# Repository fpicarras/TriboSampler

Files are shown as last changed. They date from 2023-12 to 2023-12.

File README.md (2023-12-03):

# Portable Sampler for Textile Triboelectric Nano-Generators (TENGs) Wearable Sensor System

## Overview

Textile triboelectric nano-generators (TENGs) have emerged as a promising solution for wearable self-powered sensing technology. These flexible TENGs exhibit stable output performance under strong deformation and can be utilized as wearable sensors to monitor biomechanical movements. In this internship project, we focused on the conceptualization of a small, portable electronic device capable of harnessing signals produced by TENGs as sensors and processing the acquired data.

## Objectives

The primary goal of this internship was to explore the potential of TENGs as wearable sensors and to design a system that efficiently captures and transmits the biomechanical movement data.

## Challenges and Solutions

Despite the initial aim of achieving self-sustainability for the electronic device using TENGs, practical limitations were encountered. As a result, we decided to design a low-power and low-profile system powered by two single coin batteries. This system is capable of sampling the sensor data and transmitting it to another device with higher processing capabilities, allowing for more efficient real-time data management.

## System Design

The designed system consists of:
- **Textile Triboelectric Nano-Generators (TENGs):** Serving as wearable sensors to capture biomechanical movement data.
- **Low-Power Circuit:** Powered by two single coin batteries, capable of efficiently sampling the sensor data.
- **Data Transmission:** The system transmits captured data to another device with higher processing capabilities for real-time management.

## Future Considerations

Although the current implementation relies on coin batteries for power, future iterations may explore alternative power sources or energy-efficient improvements to enhance device sustainability.

## Usage

To utilize the system:
1. **Wear the TENGs:** Attach the TENGs to the desired wearable locations.
2. **Power On:** Ensure the low-power circuit is powered by two single coin batteries.
3. **Data Transmission:** The system will transmit the captured data to another device for real-time monitoring.

## Conclusion

This internship project lays the foundation for the development of a wearable sensor system utilizing TENGs for biomechanical movement monitoring. While the goal of achieving complete self-sustainability remains a future consideration, the current design provides a practical and efficient solution for real-time data management in everyday and medical environments.

**Note:** This README serves as a high-level overview. Refer to the project documentation for detailed technical information and instructions.

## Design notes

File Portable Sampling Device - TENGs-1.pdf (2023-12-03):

# Portable Sampling Device for textile-embedded Triboelectric Nanogenerators Sensors

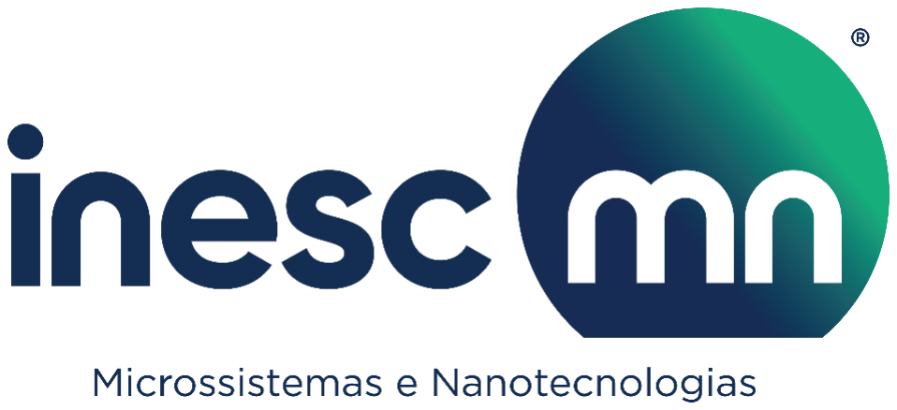
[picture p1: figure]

## Filipe Piçarra

### Ismael Domingos

### Summer Internship at INESC-MN

### Triboelectric Nanogenerators for self-sustainable Wearable Electronics

### August 2023

# Index

## Introduction

Textile triboelectric nano-generators (TENGs) are emerging as a promising solution for wearable self-powered sensing technology. The flexible TENG presents a stable output performance under strong deformation and its sensitivity to movement can be explored as wearable sensor to monitor biomechanical movements. In this Internship, we engaged in the conceptualization of small portable electronic device that could harness the signals produced by the TENGs acting as sensors to further process the data.

While the self-sustainability of the circuit proved unfruitful to power said device, for now, we opted in designing a low-power and low-profile system powered by two single coin batteries who could be able to sample the sensors data and transmit it to another device with higher processing capabilities to more efficiently manage said data in real-time, allowing the users to better track biomechanical movements in a every-day or medical environment.

## Methodology

Throughout the conceptualization and testing of the devices, the following instruments were used:

- Tektronix TBS 1000C Series Digital Oscilloscope
- Agilent 33210A Function Generator
- TriboTester – Perpendicular Oscillatory Movement Stimulator
- Arduino Uno – ADC used to sample the output signal. 10-bit 0 to 5 V ADC with an input impedance of 10 MΩ.

The circuits were tested in TENGs with single electrode configuration, where the sensors were labelled has the positive electrode and another textile surface as it’s negative/reference counterpart.

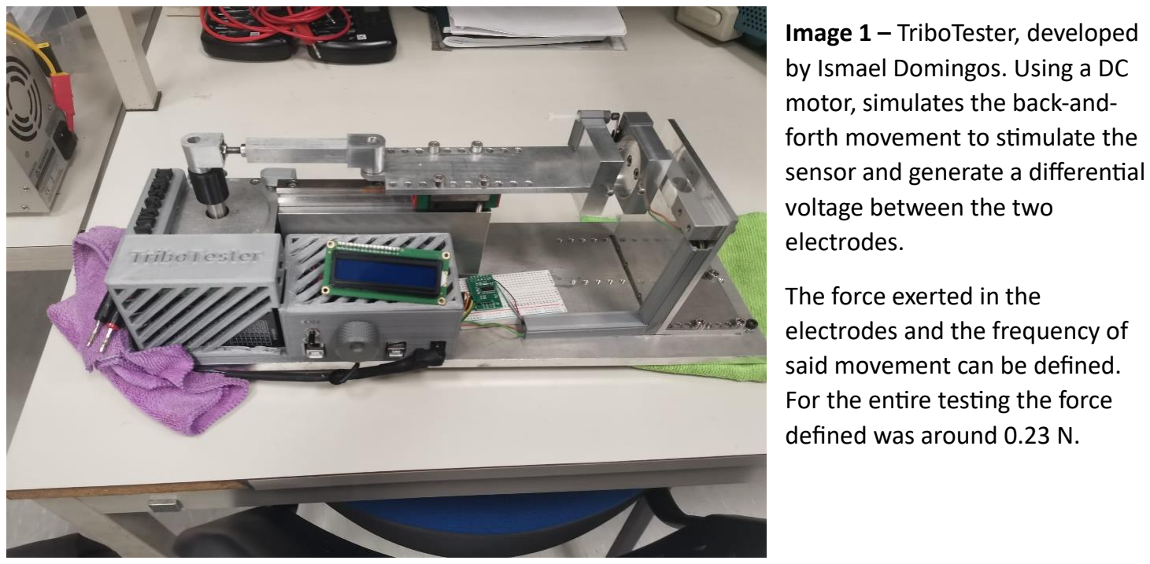
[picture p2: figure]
Image 1 – TriboTester, developed by Ismael Domingos. Using a DC motor, simulates the back-and- forth movement to stimulate the sensor and generate a differential voltage between the two electrodes.; The force exerted in the electrodes and the frequency of said movement can be defined. For the entire testing the force defined was around 0.23 N.

## Conceptualization

Has shown in the research made by Ismael Domingos and his team, on “Printed graphene electrodes for textile-embedded triboelectric nanogenerators for biomechanical sensing”, we can observe that the higher the resistive load on the TENG, the higher were the voltage spikes observer when the sensor was cautiously stimulated.

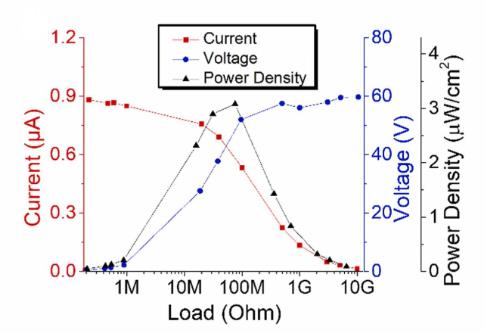
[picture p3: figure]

Thus, the first premiss of the solution was set out: the circuit’s input impedance had to be around 10 MΩ. This way we could achieve signals strong enough (expected peak value of around 20 V) to be greatly defined when sampled, even after conditioning to fit in the ADC range, whilst maintaining a high power density.

The average ADC has a range of 0 to 5V, meaning if the input signal is not within this range the ADC will saturate, so the process would be to make a signal fit this range. For this we would have to attenuate the output to ±2,5 V and add a offset of 2,5 V.

The first circuit consisted of a simple voltage divider with a pull-up resistor. The idea beyond it was that the AC signal (sensor signal) would see a voltage divider and a constant voltage would be applied to establish a DC resting point for the circuit.

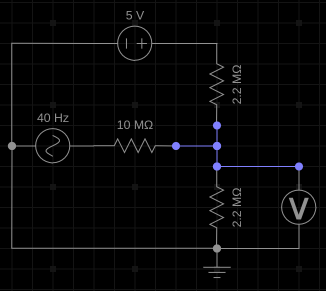
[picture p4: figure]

In theory, if we define the voltage source in this schematic as the sensor, the problem would be solved, however, we were interpreting the ADC as device with infinite input impedance. On normal circuits that would be the case, but since we are working with such high impedance resistors the ADC can´t be ignored as just a “voltmeter” and as to be considered as a resistor to ground.

Image 2 – Current, Voltage and Power Density in relation to the load seen by the TENG.

Image 3 – First circuit conceptualized. Embodies a theoretical resolution of the conditioning problem.

To fix this issue, a buffer was introduced between the output signal and the ADC, using a OPA340PA operational amplifier. The idea behind a buffer is that, when externally powered, it has a near infinite input impedance and can output the voltage in it´s input without affecting the circuit it’s reading from.

In these conditions, given that the circuit is being powered by the 5 V output of the Arduino Uno and we have no negative voltage in this simpler solution, the Amplifier is limited to and input and output of around 0 to 5 V, but since the signal received would be already conditioned to the ADC, this won’t be a problem.

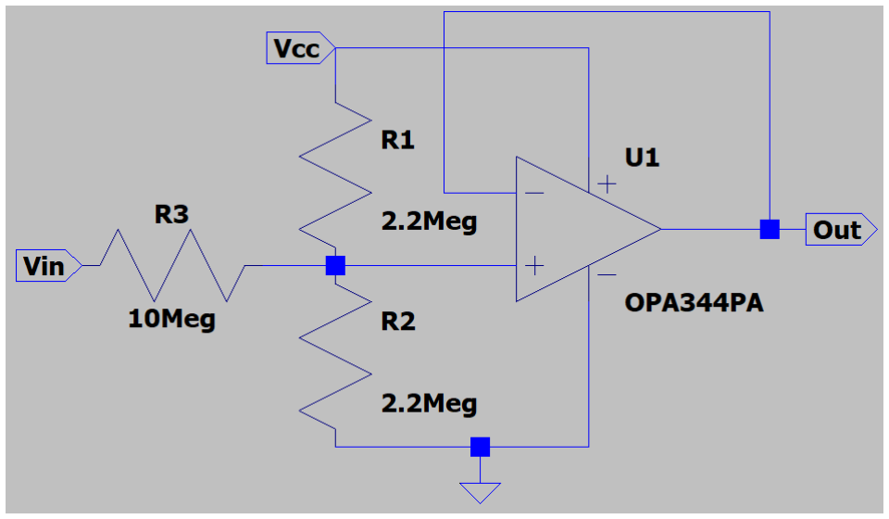
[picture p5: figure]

Image 4 – Second design used and tested; the addition of the buffer fixed the interference that the ADC caused in the resistors balance.

The following results were obtained stimulating the circuit using the Wave Function Generator, the signal had a frequency of 10 Hz (near the expected maximum frequency of biomechanical motion) and variable amplitude:

As shown in the
graph the circuit
proved to have an
unstable gain, thus an
unstable output, with
weak signal. Meaning
less precision when
measuring small

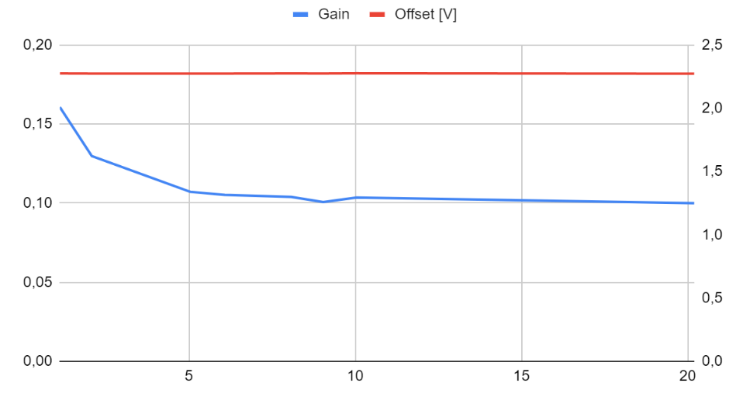
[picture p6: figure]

voltages in the sensors. A steady Offset value is a good indicator because in this way the signal can be more efficiently corrected digitally back to its original form.

Image 5 - Gain & Offset in relation with input voltage (peak-to-peak) [V]

However, when the circuit was tested with a sensor sample in the TriboTester for the first time the results proved unfruitful. The output signal was very weak and was mixed with noise to a point were actual weak signal generated by the sensors were unrecognisable. Discussing the problem, we came to the conclusion that there was a strong presence of noise deriving from the electrical network.

A band-stop filter was introduced between the buffer and the ADC to cutoff spectral components of 50 Hz (Anti-Hum filter for the European Electrical Network). A decoupling capacitor was also placed in the input, to filter any DC component of the sensor’s signal.

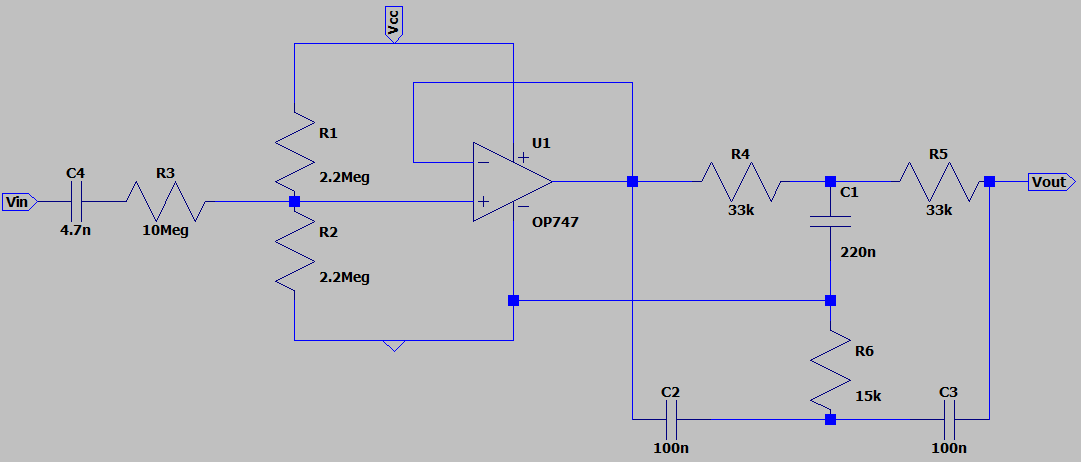
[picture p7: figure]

Image 6 – Third circuit used and tested; a decoupling capacitor and a band-stop (50 Hz) filter were added to better condition the signal and the output, respectively.

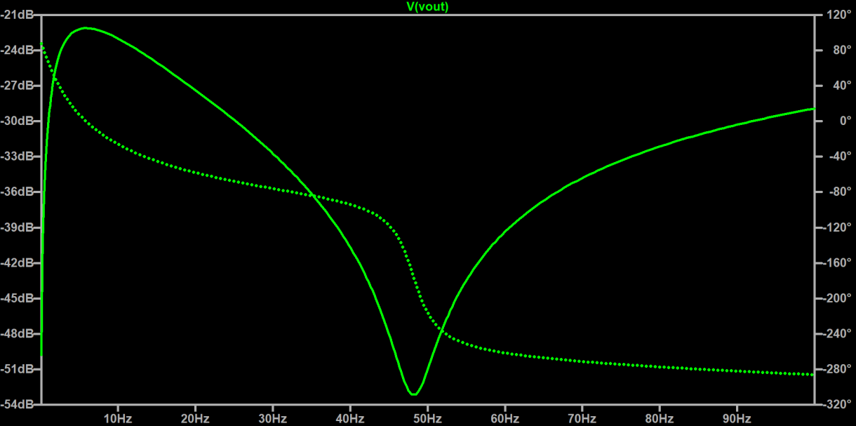
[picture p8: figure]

Image 7 – Spectral Analysis (using LTSpice software) of the output voltage, solid green line represents the Voltage gain in logarithmical scale and dotted line the output’s phase shift; as expected, there is a significand drop in the gain in the frequencies surrounding the 50 Hz and in the very low frequencies (DC components).

When tested
with the Wave function
Generator, it’s important
to note a significant
improvement when it
comes to the precision
of weaker signals.

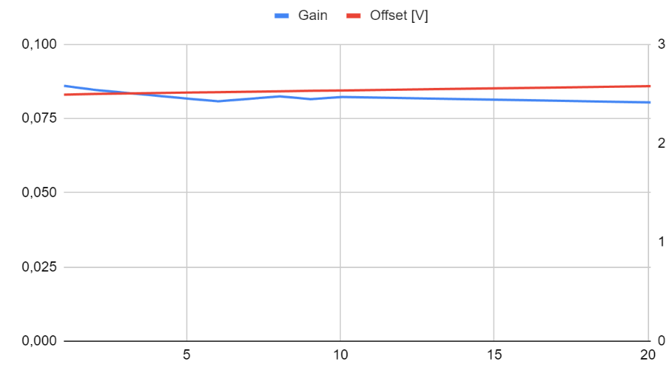
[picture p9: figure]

However, once again when the tested with samples in the TriboTester, the outputted signal was still very noisy and weak, even with the 50 Hz filter applied, meaning that the noise source lied elsewhere.

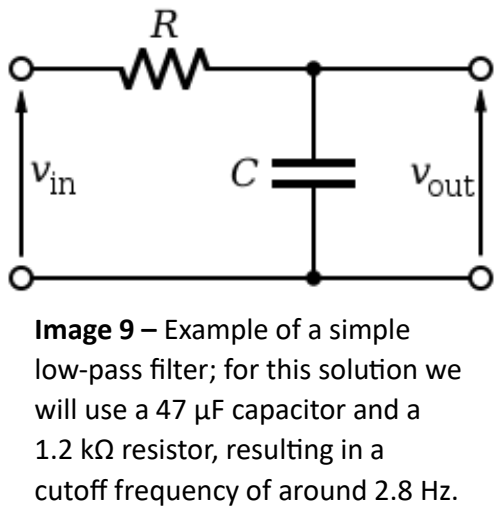
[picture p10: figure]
Image 9 – Example of a simple low-pass filter; for this solution we will use a 47 μF capacitor and a 1.2 kΩ resistor, resulting in a cutoff frequency of around 2.8 Hz.

Given that the band-stop filter was proved
useless, it as swapped with a simple low-pass filter
with a cutoff frequency of around 2.8 Hz. This makes it that frequencies above this one have a drop of -20dB per decade, meaning signals around 28 Hz are 10 times smaller, around 280 Hz, 100 times, etc. This also ensures that the Nyquist-Shannon Sampling Theorem is respected: signal components that have a frequency higher than half of the sampling frequency, will be mirrored in lower frequencies when they are sampled by the ADC; but if filtered, this effect is greatly decreased and can even be ignored.

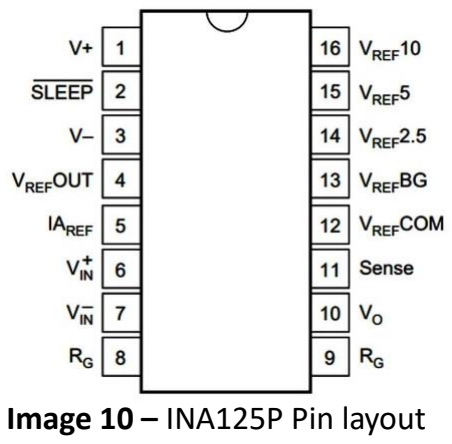
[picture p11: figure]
Image 10 – INA125P Pin layout

Until now we haven’t been considering the ambient noise that is absorbed by the sensors (and connecting wires), this noise is common to both electrodes of the sensor, meaning if we subtract the voltage in the negative electrode to the voltage in the positive electrode we should, in theory, remove the common voltage, cancelling most of the ambient noise. For this we will use the INA125P Instrumentation Amplifier (as “subtractor”), again with single supply of 0 to 5 V.

Image 8 - Gain & Offset in relation with input voltage (peak-to-peak) [V]

In this configuration the amplifier will only read inputs above 200 mV, so now both of the inputs require a DC offset, for this we will use the reference voltage pins in the IC package. The amplifier already as a gain of around 8 times (when it´s two resistor pins are connected to a 1 MΩ resistor), this means the signal has to be at least 8 times small when in enters the amplifier to compensate its gain. Using the VREFBG connected to the VREFOUT we can have a stable supply of 1.25 V that will be used to give a DC offset to both inputs, but since the output signal has to be above zero because of the supply conditions, let’s make the negative terminal have a smaller offset, make it half the offset given to the other terminal.

To fix the weak signal issue the input resistance was increased to about 505 MΩ, now the signal was strong enough to be defined when sampled, the resulting circuit is as follows:

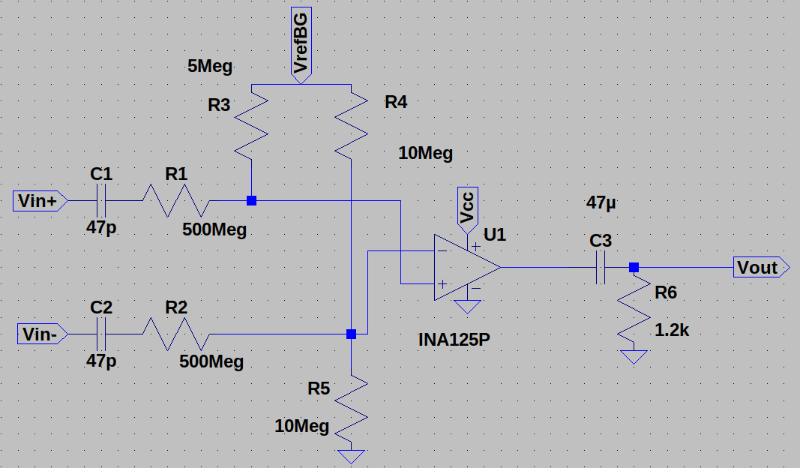
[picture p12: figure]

Image 11 – Fourth and final circuit tested and used; the addition of the subtractor and the filter allowed for a cleaner signal, whereas the increase in the input impedance allowed for stronger ones.

When we make an AC analysis (the
VREFBG is ground), both signals see the
same simple voltage divider that makes a signal around 100 times smaller (actual gain of 0.0099). But the other way around, in a DC analysis, the negative terminal as an injection of half the DC value in the
positive one, because of the 10 MΩ voltage
divider. A bypass capacitor is also present

to decouple any DC components of the signal, but with a lower capacity to accommodate for the higher impedance.

Image 12 – Output of the system (Blue) when the input (Red) is a 10 V amplitude Sine wave.

Using the data as shown in image 12 we can estimate an approximate gain by dividing the output signal’s amplitude by the input signal’s amplitude, giving us a value of around 0.013.

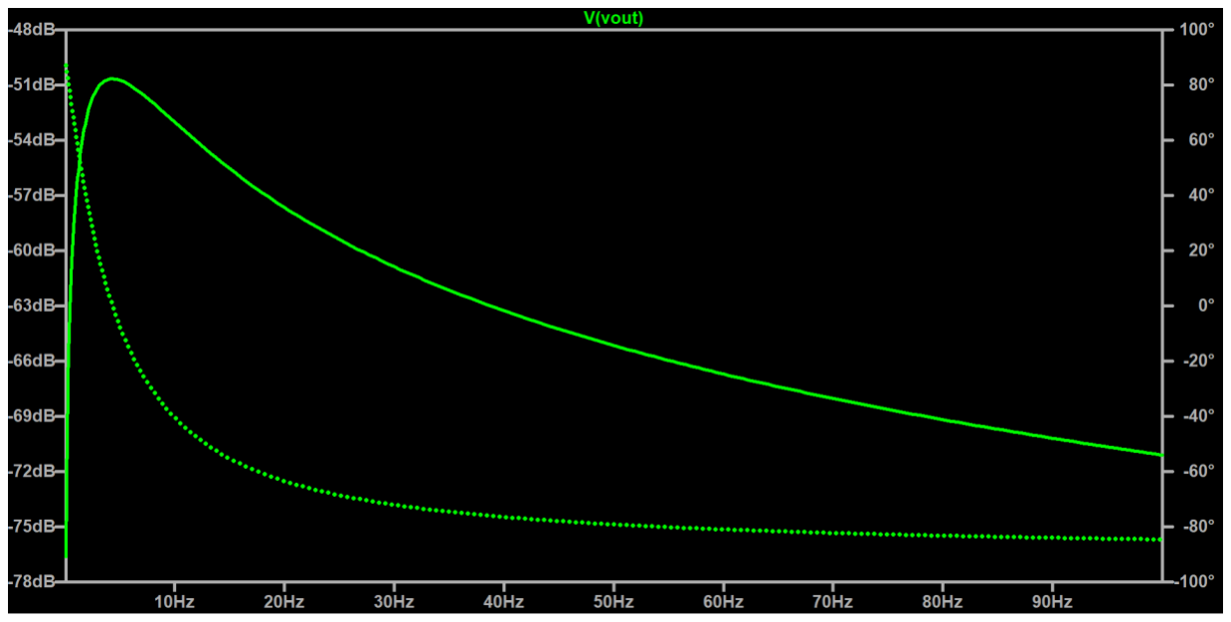
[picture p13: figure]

Image 13 – Spectral Analysis (using LTSpice software) of the output voltage, solid green line represents the Voltage gain in logarithmical scale and dotted line the output’s phase shift; as expected, the DC and higher frequency components are reduced leaving only a small band where the signal remains intact, this low frequency band is around the those of natural biomechanical movements.

Transcribing the circuit to a breadboard, the result is as follows:

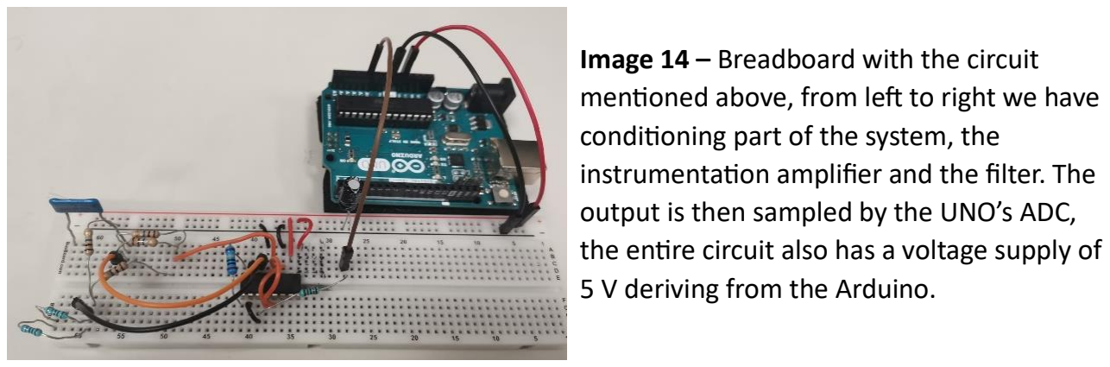
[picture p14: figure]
Image 14 – Breadboard with the circuit; conditioning part of the system, the; 5 V deriving from the Arduino.

mentioned above, from left to right we have

instrumentation amplifier and the filter. The output is then sampled by the UNO’s ADC, the entire circuit also has a voltage supply of

## Sensor-Shirt Testing

As mentioned before these sensors can be used the detect and measure biomechanical movement, whence a shirt with two TENGs near the bicep’s region (in the upper arm) were used to test the circuit in a more “real-life” scenario.

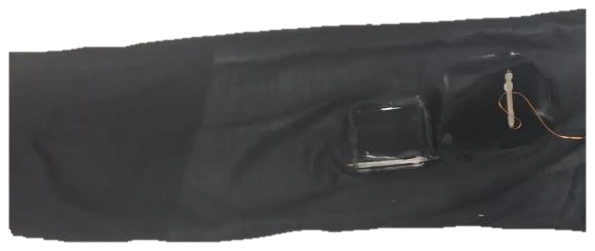
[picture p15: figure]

As seen in the image above, there are two sensors in the shirt, the only difference being that they use a different batch of adhesive (see “Printed graphene electrodes for textile-embedded triboelectric nanogenerators for biomechanical sensing” (https://www.sciencedirect.com/science/article/pii/S2211285523005256?dgcid=coauthor) for fabrication process), this later proves to be a differentiating factor between the results of the two.

For simplification purposes let’s identify each sensor:

- A – Sensor with the old adhesive.
- B – Sensor with the new adhesive.

For testing, the positive electrode would be the copper wire connected to the sensor and the negative would be its counter surface, the textile fabric in the lower arm, they would be connected to their respective pins in the circuit (image 11). The executed movement would be as shown in the image to the
right. In this configuration extending the muscle will result in a
positive varition and the other way around when flexing.

Two tests were made for each sensor, using our device still in the breadboard to condition the signal and the oscilloscope to measure it, one would test the sensor’s behavior to strong motion, and another to a weak one. For better understanting let us imagine the devices being used in a phisical therapy enciorment, we have to undertsand how the sensor would react to a person who barely has any strenght to flex their arm.

It's important to note that now the importance here isn’t much on the signal’s strengh and fidelity but on how defined it is and how well it can be distinguished from noise, to later be efficiently processed.

Image 15 – Sleeve of the shirt with the two TENGs; the one to the left has a cable soldered that runs to the zone near the collar-bone, the other has it’s terminal exposed (as seen by the copper wire).

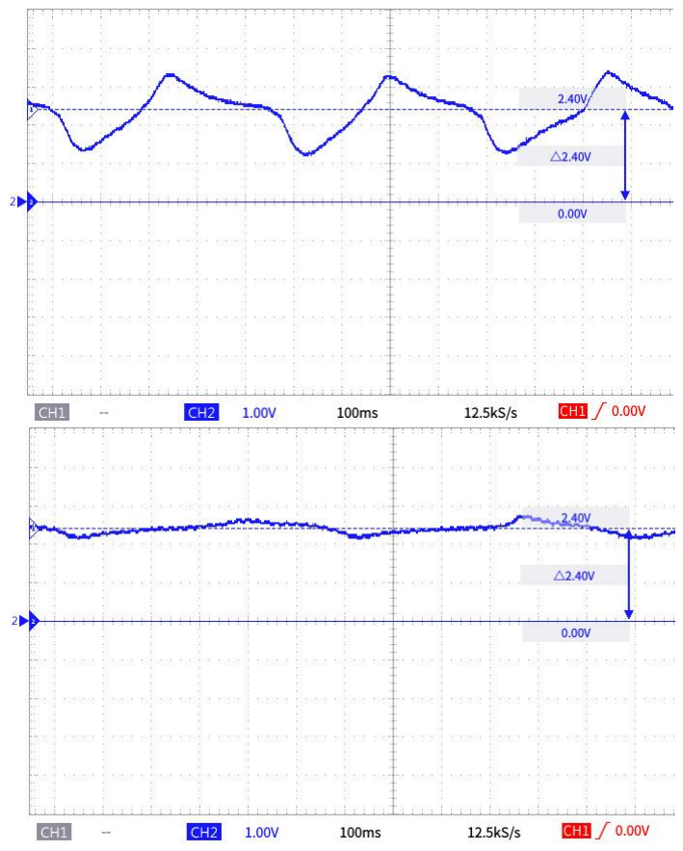
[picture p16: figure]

It is easy to conclude that sensor A showed by far the greatest results. The signal is well defined and distinguished from the noise, so when it’s digitally converted back to it’s original form it can be easly processed.

As for B, we can spot the
movement happening but weaker signals might get lost in the noise.

In this test there is no
doubt that sensor A proved to be the most effective in
converting biomechanical
motion in a voltage between the electrodes. It is evident that weak signals in sensor B get almost lost in the noise.

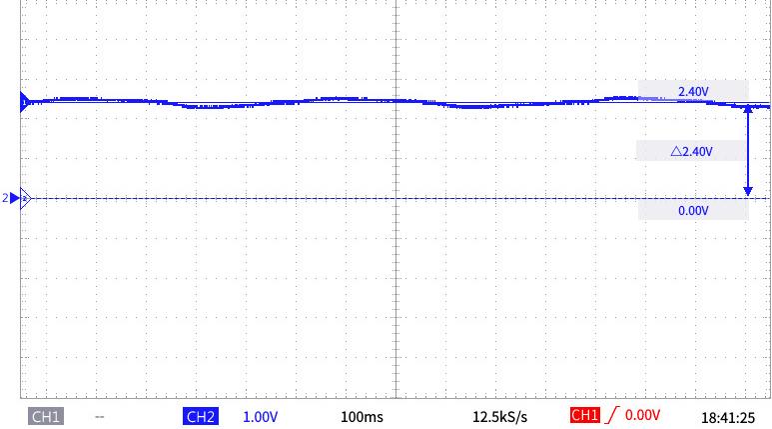
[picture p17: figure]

In conclusion these tests
gave us an idea of what a signal would look like in an actual “real-world” scenario and how we can use that information to process the data in real-time.

Images 16 & 17 – Output of the circuit when applying a normal force while extending the muscle to sensor A and B respectively.

Images 18 & 19 – Output of the circuit when applying a weaker

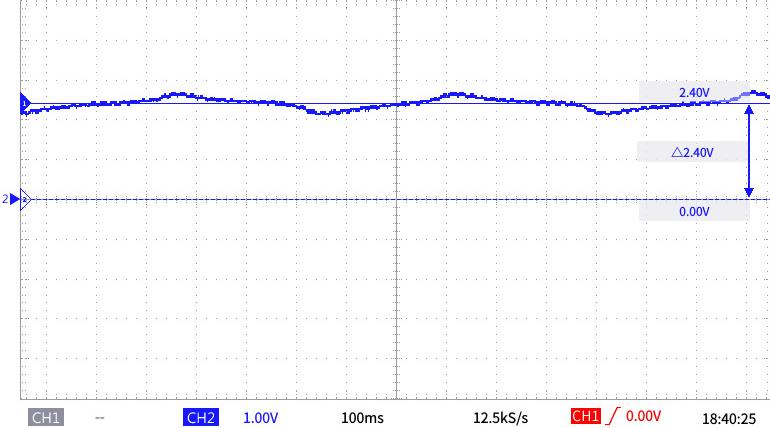
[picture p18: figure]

force while extending the muscle to sensor A and B respectively.

## TriboSampler

## Circuit Design

There is no doubt about the practicality of this circuit on a breadboard. The initial idea was to have a small sampling device to read the sensors output, on this note, we have to make this system portable, smaller, and wireless. Being so we will make the power supply two small coin cell batteries, and the microcontroller (and ADC) will be a SEEEDuino XIAO ESP-C3, capable of establishing a Bluetooth and Internet connection to communicate the data.

Using KiCad, a circuit was design based on the previously design one, to be later fabricated as a PCB, this small new design is about 4x6 cm²
, powered by two
2032-coin-cell batteries (2* 3 V) and capable of transmitting data either through Bluetooth or Wi-Fi connection, while still being able to power and communicate with other I²C devices, like a Liquid Crystal Display. The result was the following board:

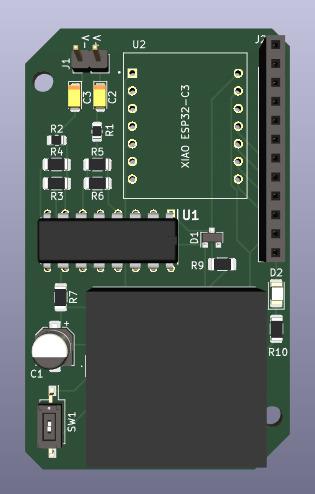
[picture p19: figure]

The material list is as follows:

- R1 & R2 – 500 MΩ SMD Resistor (2012 Metric)

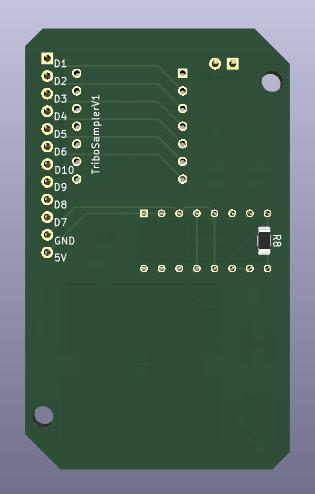
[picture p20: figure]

- R3, R4, R5 & R6 – 10MΩ SMD Resistor (3216 Metric)
- R7 – 1.2 kΩ SMD Resistor (3216 Metric)
- R8 – 1 MΩ SMD Resistor (3216 Metric)
- R9 – 100 Ω SMD Resistor (3216 Metric)
- R10 – 1.2 kΩ SMD Resistor (3216 Metric)
- C1 – 47μF SMD Electrolytic Capacitor (5x5.4)
- C2 & C3 – 47 pF SMD Tamtalum Capacitor (Kemet-I 3216 Metric)

Image 20 – Front and Back view of the PCB

- D1 – 5.1 V Zener Diode (SOT-23 ANK)
- D2 – LED SMD (3216 Metric)
- BT1 – Battery Holder Keystone 1062
- J1 – 01x02 Vertical Connector PinHeader (2.54 mm)
- J2 – 01x12 Vertical Connector PinSocket (2.54 mm)
- SW1 – Button Switch SMD Omron A6S-1101-H (1 circuit)
- U1 – INA125P
- U2 – XIAO ESP32-C3

## Case

To accommodate the circuit a case was 3D printed using grey PLA filament, the dimensions are as follows: 4x6x3 cm³
. It is divided in two halves, the lower half has pins made for sliding in the circuit trough the screw holes, said pins are used to later stick on the top half. A hole was inserted in the lower half to pass the input signal cables.

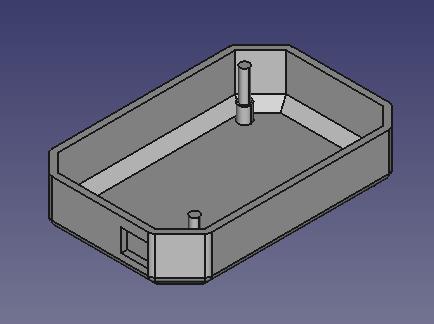
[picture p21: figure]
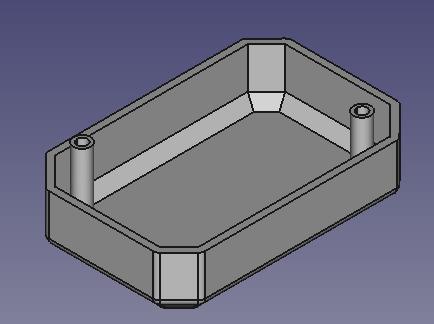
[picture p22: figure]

Image 21 – 3D models of the lower and bottom halves of the case, made in FreeCad.

Image 22 – Finished and Polished 3D printed case.

## Circuit Specifications

Conditioning
- Input Impedance - RIN ≈ 505 MΩ
- Input Amplitude Range – VIN ∈ [0.019, 130] V
- Lower Voltage Limit set by the ADC’s precision.
- Upper Voltage Limit set by Amplifier limit.
- Bandwidth - ƒIN ∈ ]0, 10] Hz
- Lower frequency limit set by Decoupling Capacitor.
- Upper frequency limit set by Output Low-pass Filter.
- Gain – G = 0.0128894
- Offset – Off = 2.4615
- Amplifier Noise – nRMS = 40 nV/√Hz
- Given the Bandwidth, the expected noise RMS in the amplifier output is ≈ 126.4 nV.

## Real Value: VOUT =

## VADC − Off

G

Sampling
- ADC Range – LSB = 224 μV
- ADC Noise - nRMS = 64. 7 μV

Microcontroller
- CPU – 32-bit RISC-V
- Clock – Up to 160 MHz
- SRAM – 400 KB
- Flash Mem – 4 MB
- Communication
- Wi-Fi subsystem – Complies with IEEE 802.11b/g/n protocol and supports Station mode, SoftAP mode, SoftAP + Station mode, and promiscuous mode.
- Bluetooth – Supports features of Bluetooth 5 (BLE) and Bluetooth mesh.
- USB-C Connection
- Ultra-Low Power – Deep sleep power consumption is about 43 μA

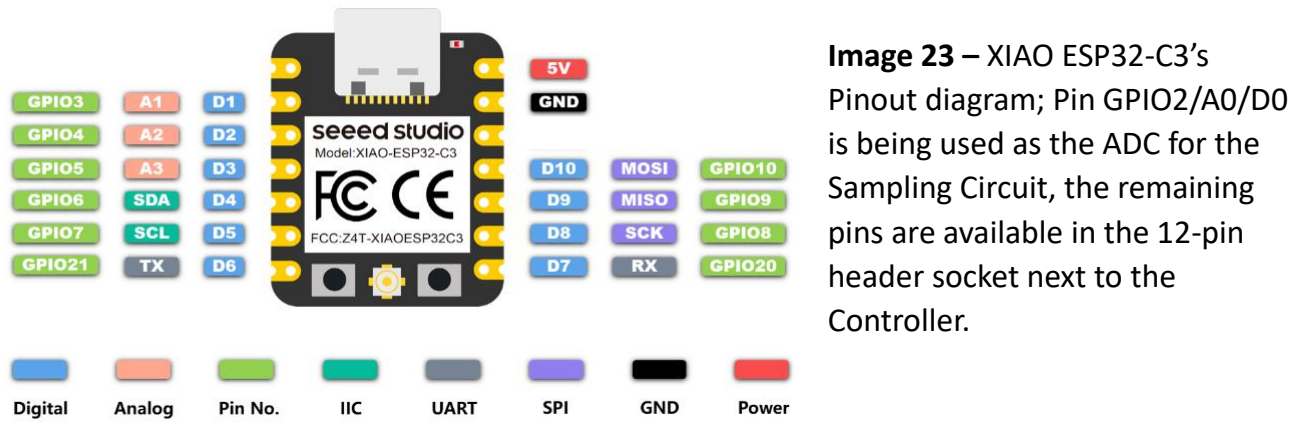
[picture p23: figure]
Image 23 – XIAO ESP32-C3’s Pinout diagram; Pin GPIO2/A0/D0 is being used as the ADC for the Sampling Circuit, the remaining pins are available in the 12-pin header socket next to the Controller.

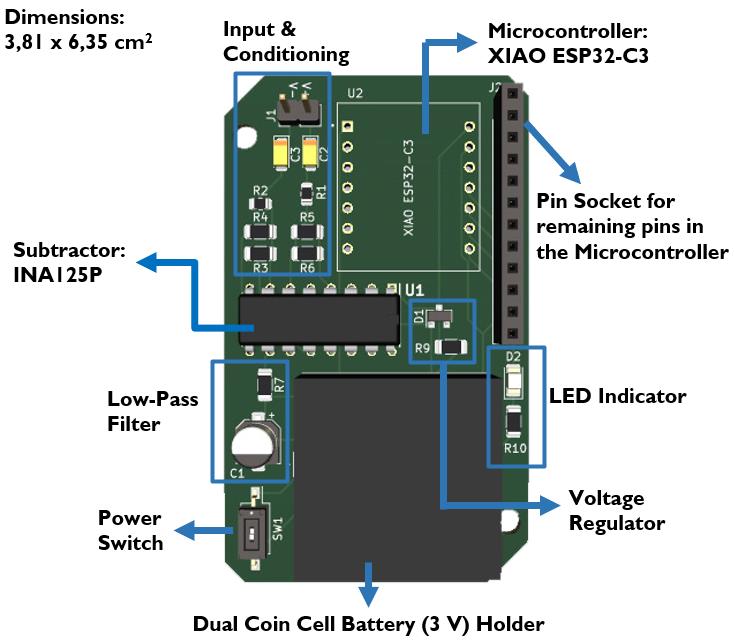
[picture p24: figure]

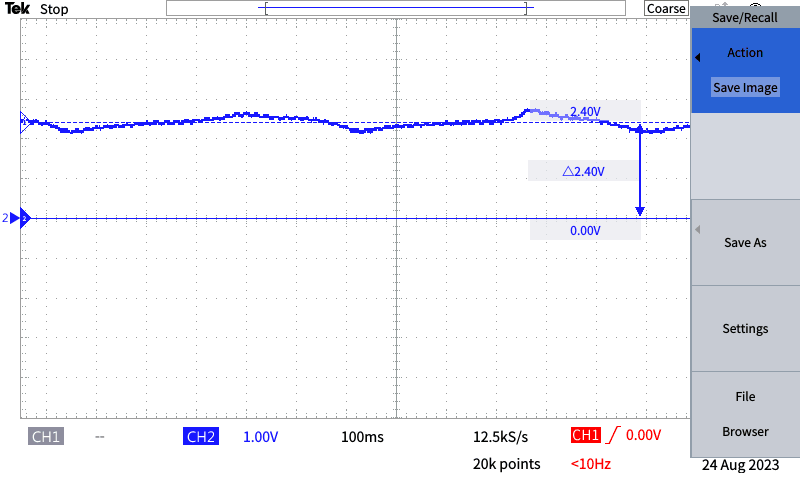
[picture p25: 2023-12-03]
TriboeletricSampler-KiCad/images/TEK00002.PNG

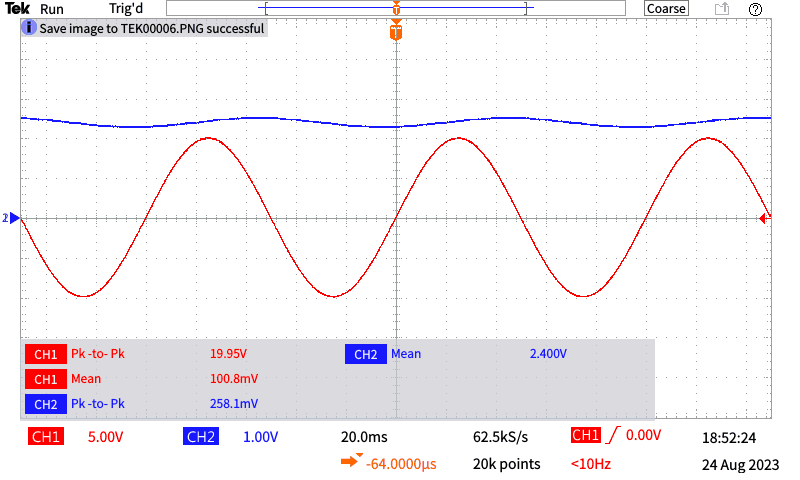
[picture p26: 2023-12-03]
TriboeletricSampler-KiCad/images/TEK00007.PNG

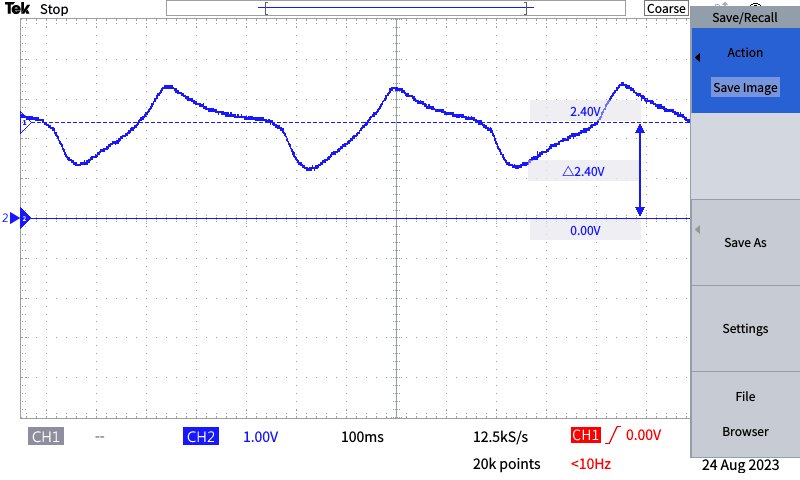
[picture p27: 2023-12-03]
TriboeletricSampler-KiCad/images/TEK00001.PNG

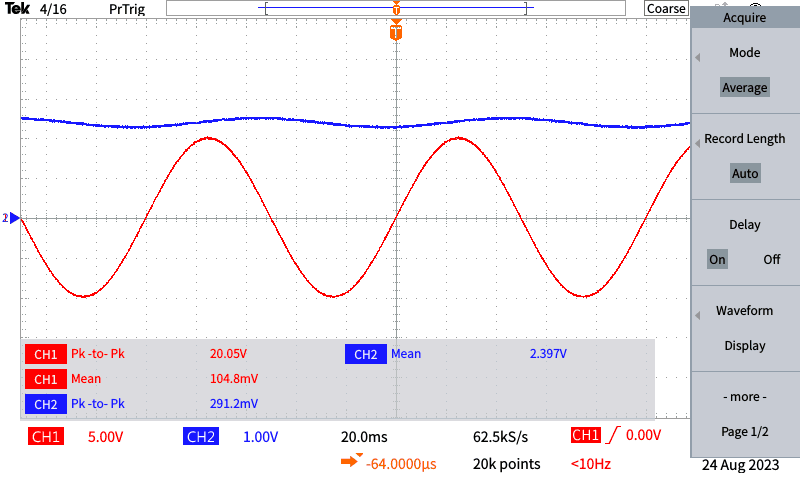
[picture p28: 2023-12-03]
TriboeletricSampler-KiCad/images/TEK00006.PNG

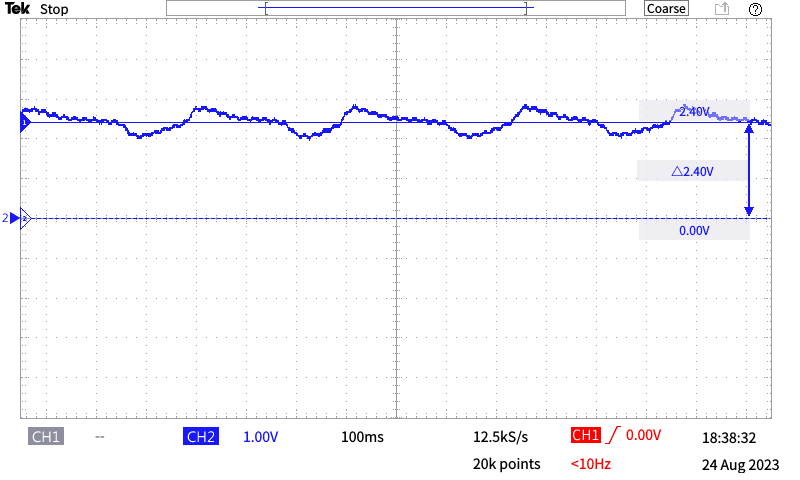
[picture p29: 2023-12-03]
TriboeletricSampler-KiCad/images/TEK00003.PNG

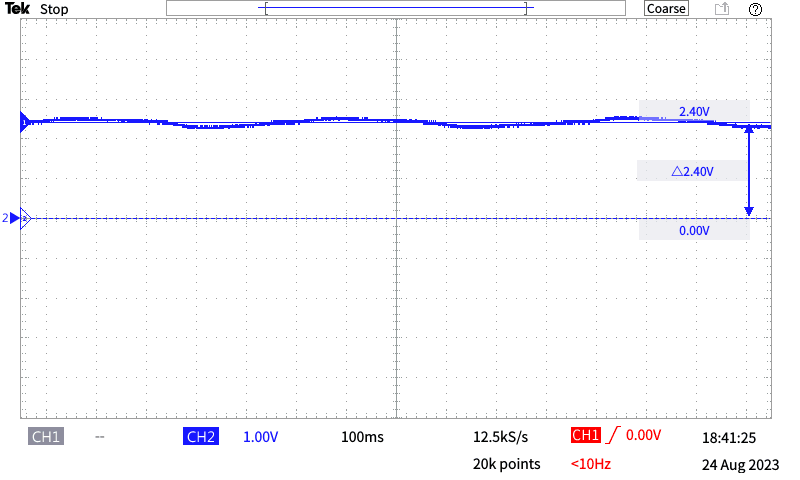
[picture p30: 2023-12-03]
TriboeletricSampler-KiCad/images/TEK00005.PNG

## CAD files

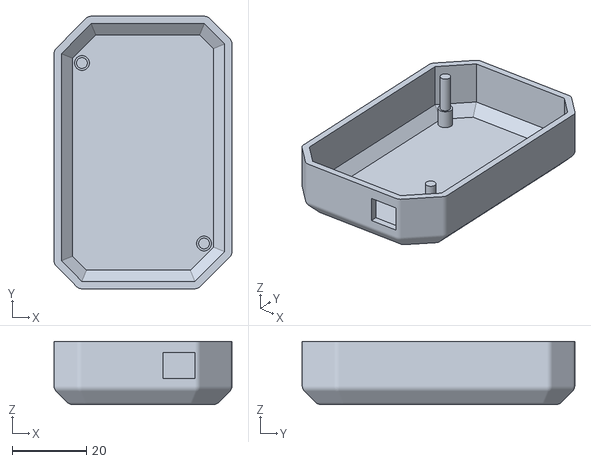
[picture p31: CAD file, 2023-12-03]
TriboeletricSampler-KiCad/Casing Models/lower_body.stl
48.0 x 73.5 x 17.0

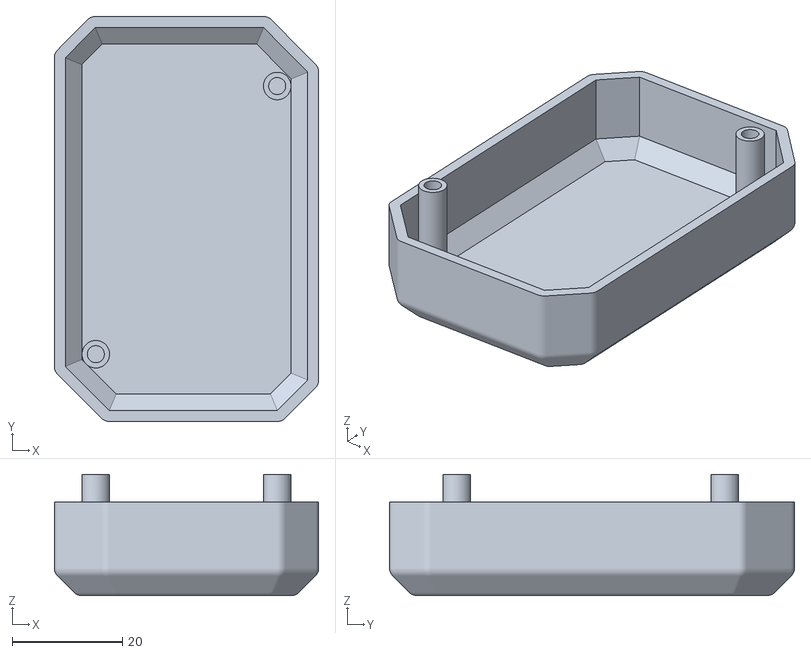
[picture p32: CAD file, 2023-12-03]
TriboeletricSampler-KiCad/Casing Models/upper_body.stl
48.0 x 73.5 x 22.0

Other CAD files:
TriboeletricSampler-KiCad/casing_lower_V1.FCStd
TriboeletricSampler-KiCad/casing_upper_V1.FCStd

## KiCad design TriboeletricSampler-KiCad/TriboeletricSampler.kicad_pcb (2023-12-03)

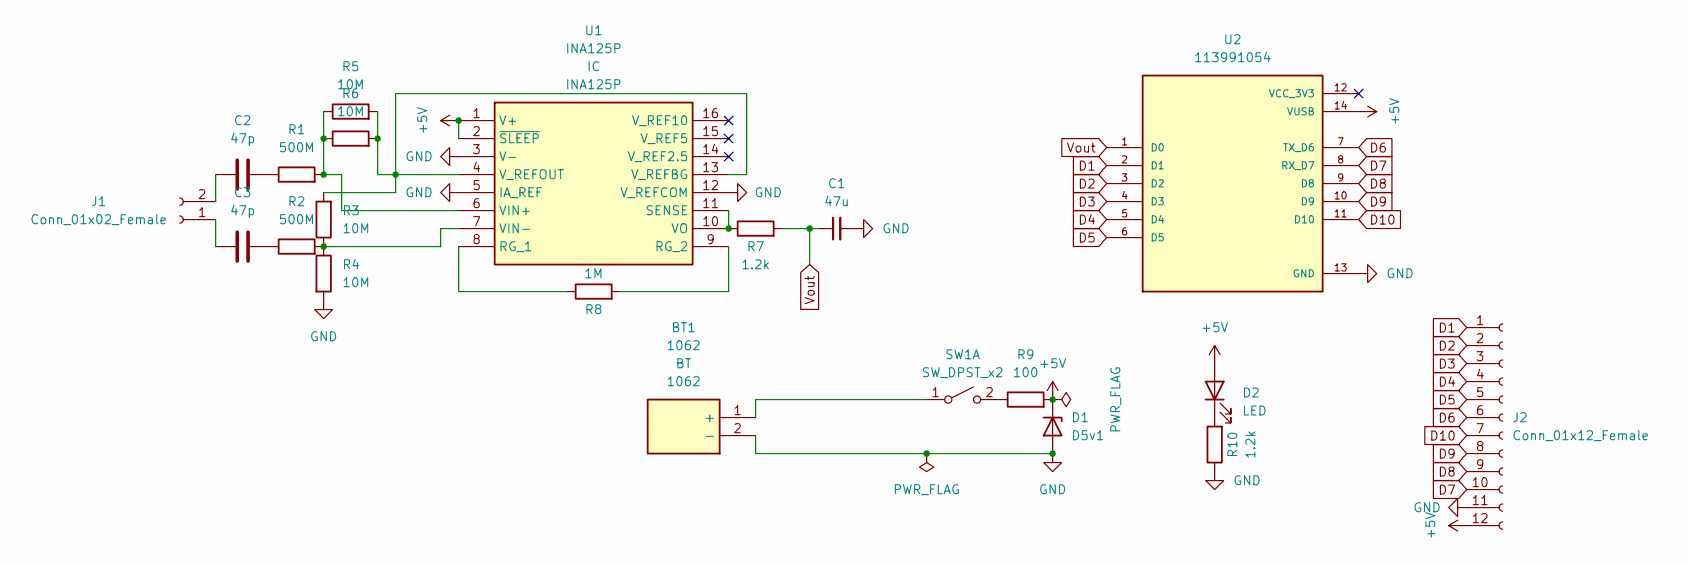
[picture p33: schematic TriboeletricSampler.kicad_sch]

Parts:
BT1: 1062; Mouser Part Number 534-1062
C1: 47u; CP_Elec_5x5.4
C2, C3: 47p; CP_EIA-3216-10_Kemet-I
D1: D5v1; D_SOT-23_ANK
D2: LED; LED_1206_3216Metric
J1: Conn_01x02_Female; PinHeader_1x02_P2.54mm_Vertical
J2: Conn_01x12_Female; PinSocket_1x12_P2.54mm_Vertical
R1, R2: 500M; R_0805_2012Metric
R3, R4, R5, R6: 10M; R_1206_3216Metric
R7, R10: 1.2k; R_1206_3216Metric
R8: 1M; R_1206_3216Metric
R9: 100; R_1206_3216Metric
SW1: SW_DPST_x2; SW_DIP_SPSTx01_Slide_Omron_A6S-110x_W8.9mm_P2.54mm
U1: INA125P; DIP794W53P254L1930H508Q16N; Mouser Part Number 595-INA125P
U2: 113991054; MODULE_113991054; PARTREV 23/05/2022

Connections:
+5V: D1.1 (K), D2.2 (A), J2.12, R9.2, U1.1 (V+), U1.2 (~SLEEP), U2.14 (VUSB)
D1: J2.1, U2.2 (D1)
D2: J2.2, U2.3 (D2)
D3: J2.3, U2.4 (D3)
D4: J2.4, U2.5 (D4)
D5: J2.5, U2.6 (D5)
D6: J2.6, U2.7 (TX_D6)
D7: J2.10, U2.8 (RX_D7)
D8: J2.9, U2.9 (D8)
D9: J2.8, U2.10 (D9)
D10: J2.7, U2.11 (D10)
GND: BT1.2 (-), C1.2, D1.2 (A), J2.11, R4.2, R10.1, U1.3 (V-), U1.5 (IA_REF), U1.12 (V_REFCOM), U2.13 (GND)
unnamed: BT1.1 (+), SW1.1 (A)
unnamed: D2.1 (K), R10.2
unnamed: C3.1, J1.1
unnamed: C2.1, J1.2
unnamed: C2.2, R1.1
unnamed: R1.2, R5.1, R6.1, U1.6 (VIN+)
unnamed: C3.2, R2.1
unnamed: R2.2, R3.1, R4.1, U1.7 (VIN-)
unnamed: R3.2, R5.2, R6.2, U1.4 (V_REFOUT), U1.13 (V_REFBG)
unnamed: R7.1, U1.10 (VO), U1.11 (SENSE)
unnamed: R8.1, U1.8 (RG_1)
unnamed: R8.2, U1.9 (RG_2)
unnamed: R9.1, SW1.2 (B)
Vout: C1.1, R7.2, U2.1 (D0)

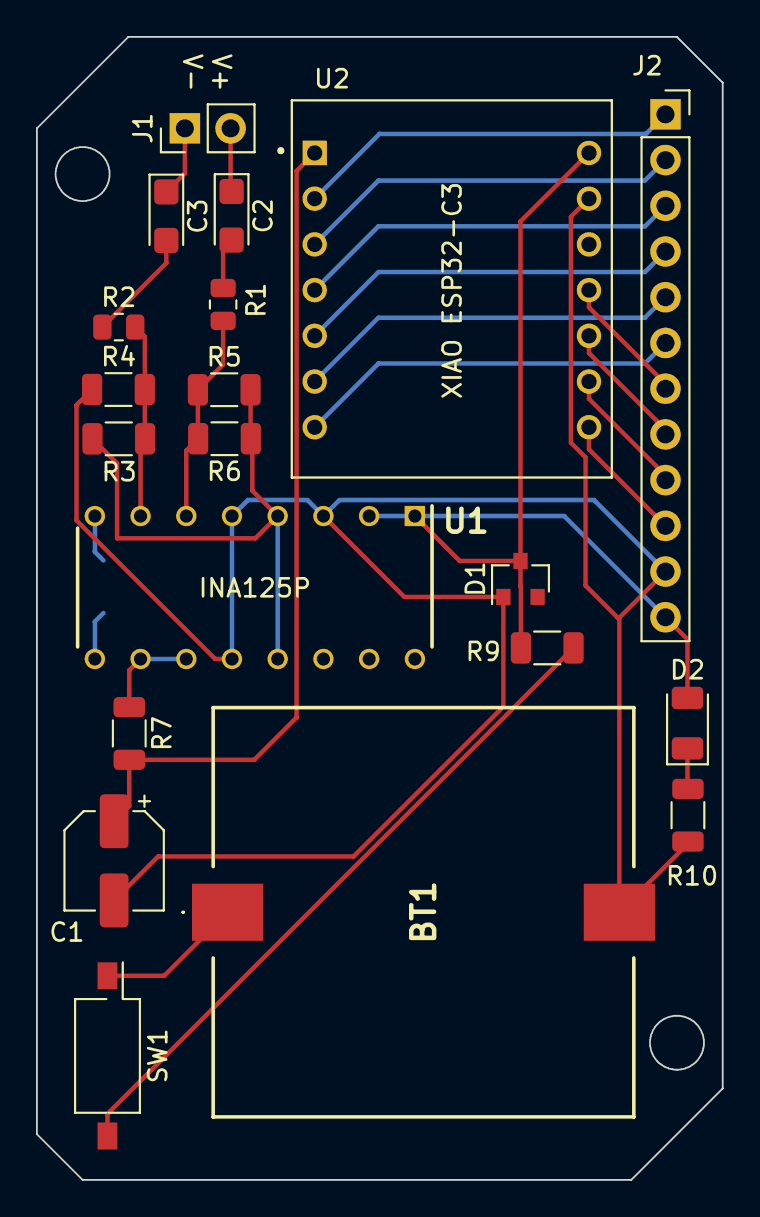
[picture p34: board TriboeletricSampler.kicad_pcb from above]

Board: 2 copper layers, 38.1 x 63.5 mm, 21 parts (1 on the bottom side), 26 nets.

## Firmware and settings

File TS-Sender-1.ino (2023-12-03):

#include <BLEDevice.h>
#include <BLEUtils.h>
#include <BLEServer.h>

#include <iostream>

// See the following for generating UUIDs:
// https://www.uuidgenerator.net/

#define DEVICE_NAME         "TriboSamplerV1"
#define SERVICE_UUID        "4fafc201-1fb5-459e-8fcc-c5c9c331914b"
#define CHARACTERISTIC_UUID "beb5483e-36e1-4688-b7f5-ea07361b26a8"

BLECharacteristic *pCharacteristic = NULL;

class MyCallbacks: public BLECharacteristicCallbacks {
    void onWrite(BLECharacteristic *pCharacteristic) {
      std::string value = pCharacteristic->getValue();

      if (value.length() > 0) {
        Serial.println("*********");
        Serial.print("New value: ");
        for (int i = 0; i < value.length(); i++)
          Serial.print(value[i]);

        Serial.println();
        Serial.println("*********");
      }
    }
};

class MyServerCallbacks: public BLEServerCallbacks {
    void onConnect(BLEServer* pServer) {
      pServer->startAdvertising(); // restart advertising
    };

    void onDisconnect(BLEServer* pServer) {
      pServer->startAdvertising(); // restart advertising
    }
};

unsigned long sampTimer = 0;
unsigned long sampleInterval = 25; //100 ms = 10Hz rate

void setup() {
  Serial.begin(115200);

  BLEDevice::init(DEVICE_NAME);
  BLEServer *pServer = BLEDevice::createServer();

  pServer->setCallbacks(new MyServerCallbacks());

  BLEService *pService = pServer->createService(SERVICE_UUID);

  pCharacteristic = pService->createCharacteristic(
                                         CHARACTERISTIC_UUID,
                                         BLECharacteristic::PROPERTY_READ |
                                         BLECharacteristic::PROPERTY_WRITE
                                       );

  pCharacteristic->setCallbacks(new MyCallbacks());

  pCharacteristic->setValue("Hello World");
  pService->start();

  BLEAdvertising *pAdvertising = pServer->getAdvertising();
  pAdvertising->start();
}

int i = 0;

void loop() {
  unsigned long currMillis = millis();
  if(currMillis - sampTimer >= sampleInterval){
    sampTimer = currMillis;
    std::string stringValue = std::to_string(analogRead(A0));
    std::string time = std::to_string(currMillis);
    stringValue = stringValue + "|" + time;
    pCharacteristic->setValue(stringValue);
  }
}

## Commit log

2023-12-03 Added KiCad files and Sender Code
    [TriboeletricSampler-B_Cu.gbl, TriboeletricSampler-B_Mask.gbs, TriboeletricSampler-B_Paste.gbp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]
2023-12-03 Project explanatory pdf and KiCad resources
